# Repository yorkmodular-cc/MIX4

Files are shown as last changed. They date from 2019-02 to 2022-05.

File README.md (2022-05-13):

# York Modular 4-channel Eurorack mixer

**This module is now discontinued - there will be no more made unless there is sufficient demand to justify a new run of boards and panels.**

[][cc-by-sa]

This work is licensed under a
[Creative Commons Attribution-ShareAlike 4.0 International License][cc-by-sa].

[][cc-by-sa]

[cc-by-sa]: http://creativecommons.org/licenses/by-sa/4.0/
[cc-by-sa-image]: https://licensebuttons.net/l/by-sa/4.0/88x31.png
[cc-by-sa-shield]: https://img.shields.io/badge/License-CC%20BY--SA%204.0-lightgrey.svg

What you'll find here:

- `gerbers` - the Gerber files are in here; if you want to fabricate your own run of boards, these are what the fab will need.
- `4ch-euromixer-BOM.xlsx` - bill of materials
- `4ch-euromixer.png` - circuit schematic for reference
- `4ch-euromixer.{dxf,fpd}` - panel files in AutoCAD format (`.dxf`) and Front Panel Designer format (`.fpd`). These are _blank_ panels.
- `4ch-euromixer-lettered.{dxf,fpd}` - as above, but appropriately lettered.
- `4ch-euromixer.stl` - OpenSCAD `.stl` file for 3D printing. Depending on the accuracy of your 3D printer, you may need to take a deburring tool to the jack and pot holes in order to get things to fit.
- `mix4-mainboard.kicad_pcb` - KiCAD board file for mainboard.
- `mix4-panel.kicad_pcb` - KiCAD board file for front panel.

If you're planning to have panels laser-cut then the DXF files are probably what you want - if your fabricator requires Adobe Illustrator or a similar format 
then importing the DXF files into a package such as Inkscape and then re-exporting them as SVG should do the trick.

If you're planning to 3D-print a panel, just pull the STL file into your package of choice (I use Cura, others are available) and tweak the settings to suit.
My own experience is that printing with PLA at 200C with a heated bed (60-70C) gives good results - whether you use a raft is a matter of personal choice; for
large panels I tend to use a 10mm raft, even on a heated bed. You don't need insanely high resolution either - 0.2mm/layer is plenty good enough and print time
is around 3hrs on my AnyCubic i3.

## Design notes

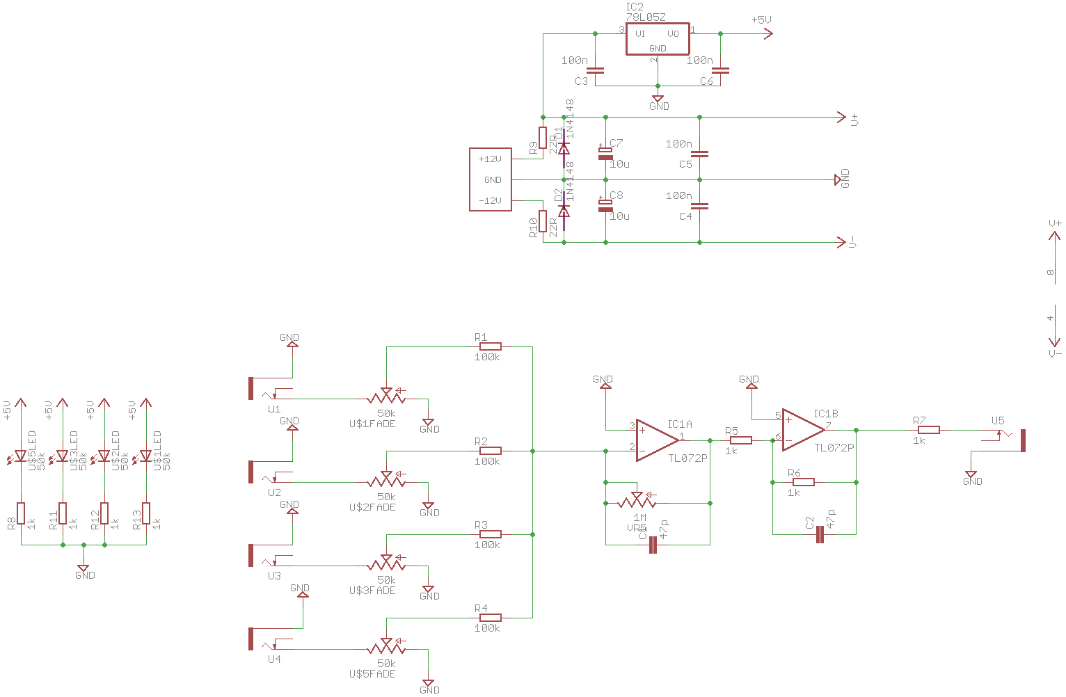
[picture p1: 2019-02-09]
4ch-euromixer.png

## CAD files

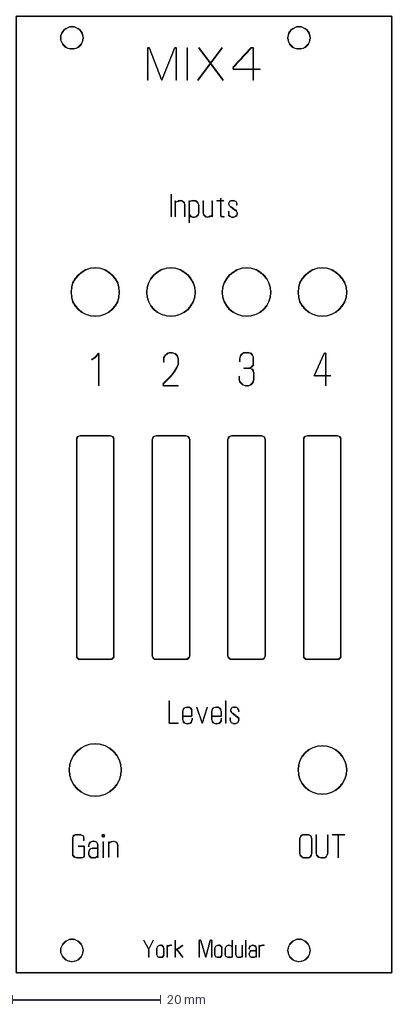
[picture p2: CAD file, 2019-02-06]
4ch-euromixer-lettered.dxf
50.5 x 128.4 mm

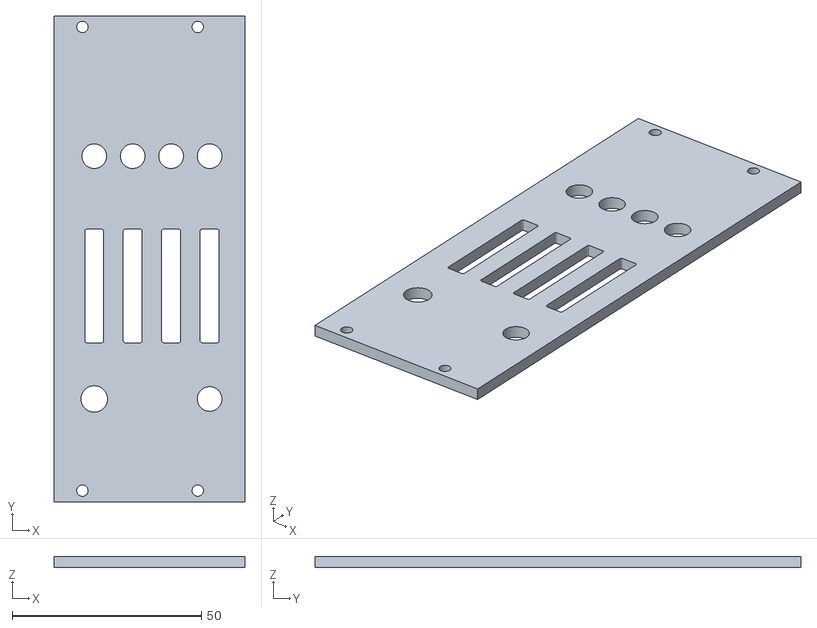
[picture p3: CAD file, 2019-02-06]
4ch-euromixer.stl
50.5 x 128.4 x 3.00

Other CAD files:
4ch-euromixer.dxf

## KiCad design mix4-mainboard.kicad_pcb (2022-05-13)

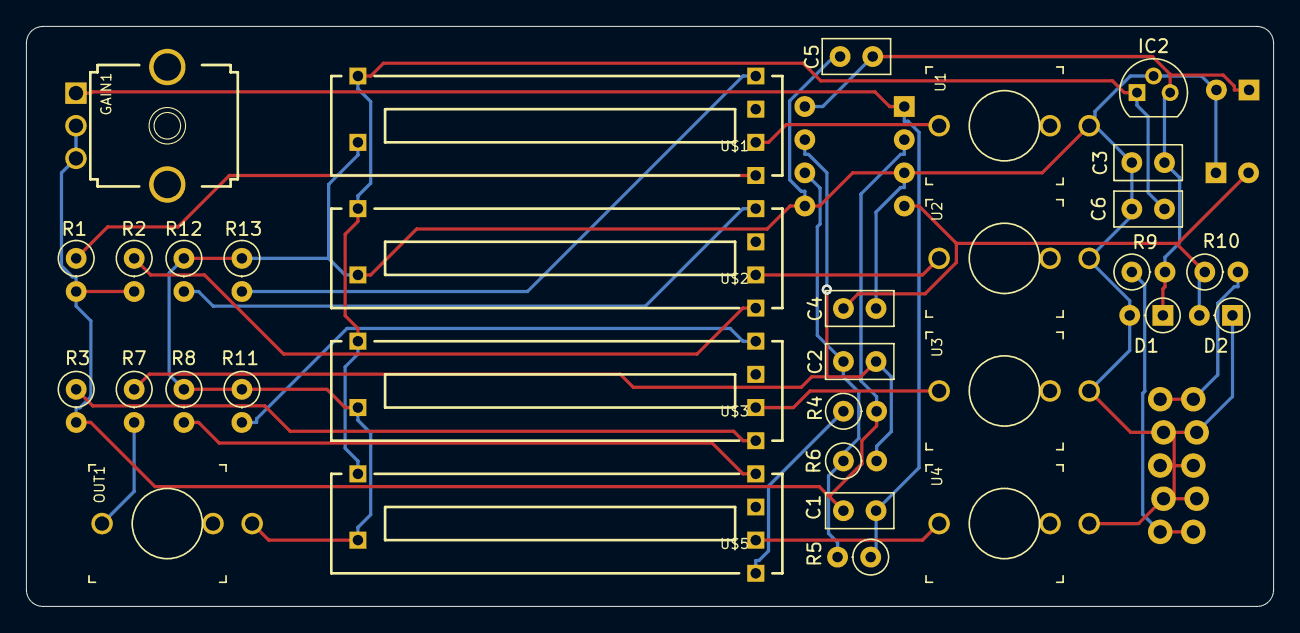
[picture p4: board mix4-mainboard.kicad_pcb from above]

Board: 2 copper layers, 95.6 x 44.4 mm, 36 parts (0 on the bottom side), 23 nets.

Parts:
C1, C2: 47p; C_Disc_D5.0mm_W2.5mm_P2.50mm
C3, C4, C5, C6: 100n; C_Disc_D5.0mm_W2.5mm_P2.50mm
C7, C8: CP; CP_Radial_D5.0mm_P2.50mm
D1, D2: D; D_DO-35_SOD27_P2.54mm_Vertical_AnodeUp
GAIN1: 1M; 9MM_SNAP-IN_POT
IC1: TL072P; DIP-8_W7.62mm_Socket
IC2: 78Z; TO-92
LOCK1: EURO_POWER_LOCK; EURO_PWR_HEADER_LOCK
OUT1: THONKICONNNEW; WQP-PJ301M-12_JACK
R1, R2, R3, R4: 100k; R_Axial_DIN0207_L6.3mm_D2.5mm_P2.54mm_Vertical
R5, R6, R7, R8, R11, R12, R13: 1k; R_Axial_DIN0207_L6.3mm_D2.5mm_P2.54mm_Vertical
R9, R10: 22R; R_Axial_DIN0207_L6.3mm_D2.5mm_P2.54mm_Vertical
U1, U2, U3, U4: THONKICONNNEW; WQP-PJ301M-12_JACK
U$1, U$2, U$3, U$5: 50k; ALPHA_ILL_FADER_20MM

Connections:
+5V: C6.2, IC2.1, U$1.B, U$2.B, U$3.B, U$5.B
GND: C3.1, C4.2, C5.1, C6.1, C7.2, C8.1, D1.2, D2.1, IC1.3, IC1.5, IC2.2, LOCK1.GND1, LOCK1.GND2, LOCK1.GND3, LOCK1.GND4, LOCK1.GND5, LOCK1.GND6, OUT1.P$3_SLEEVE, R8.1, R11.1, R12.1, R13.1, U1.P$3_SLEEVE, U2.P$3_SLEEVE, U3.P$3_SLEEVE, U4.P$3_SLEEVE, U$1.3, U$2.3, U$3.3, U$5.3
unnamed: C1.1, GAIN1.2, GAIN1.3, IC1.2, R1.2, R2.2, R3.2, R4.2
unnamed: C1.2, GAIN1.1, IC1.1, R5.1
unnamed: C2.1, IC1.6, R5.2, R6.1
unnamed: C2.2, IC1.7, R6.2, R7.1
unnamed: LOCK1.NEG1, LOCK1.NEG2, R10.2
unnamed: LOCK1.POS1, LOCK1.POS2, R9.1
unnamed: OUT1.P$1_TIP, R7.2
unnamed: R1.1, U$1.2
unnamed: R2.1, U$2.2
unnamed: R3.1, U$3.2
unnamed: R4.1, U$5.2
unnamed: R8.2, U$5.E
unnamed: R11.2, U$3.E
unnamed: R12.2, U$2.E
unnamed: R13.2, U$1.E
unnamed: U1.P$1_TIP, U$1.1
unnamed: U2.P$1_TIP, U$2.1
unnamed: U3.P$1_TIP, U$3.1
unnamed: U4.P$1_TIP, U$5.1
V+: C3.2, C5.2, C7.1, D1.1, IC1.8, IC2.3, R9.2
V-: C4.1, C8.2, D2.2, IC1.4, R10.1

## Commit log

2019-02-06 Added panel files and updated readme
    [4ch-euromixer-lettered.dxf, 4ch-euromixer.dxf, 4ch-euromixer.stl]
2021-04-17 Added Gerber files
    [MIX4-B_Mask.gbs, MIX4-B_Paste.gbp, MIX4-B_SilkS.gbo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]
2022-05-13 Add files via upload
    Add KiCAD board files for mainboard and front panel
    [mix4-mainboard.kicad_pcb, mix4-panel.kicad_pcb]

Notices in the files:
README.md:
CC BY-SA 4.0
